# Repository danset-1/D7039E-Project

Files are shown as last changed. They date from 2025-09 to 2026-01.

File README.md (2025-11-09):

# D7039E Project - Swimming Timer
Accurate timing is a crucial part of both swimming competitions and training sessions. Existing professional timing systems are often reliable, but can be very expensive and difficult to set up, making them less accessible to smaller swimming clubs or individual athletes. This creates a need for a solution that is both affordable and adaptable while expanding on the idea of modern functionality.

The purpose of this project is to design and implement a modular timing system for swimming. The system will be built to provide accurate lap timing, digital tracking, and support for swimmer identification, so that personal bests and results can be stored and displayed in real time. 

# Rough sketch
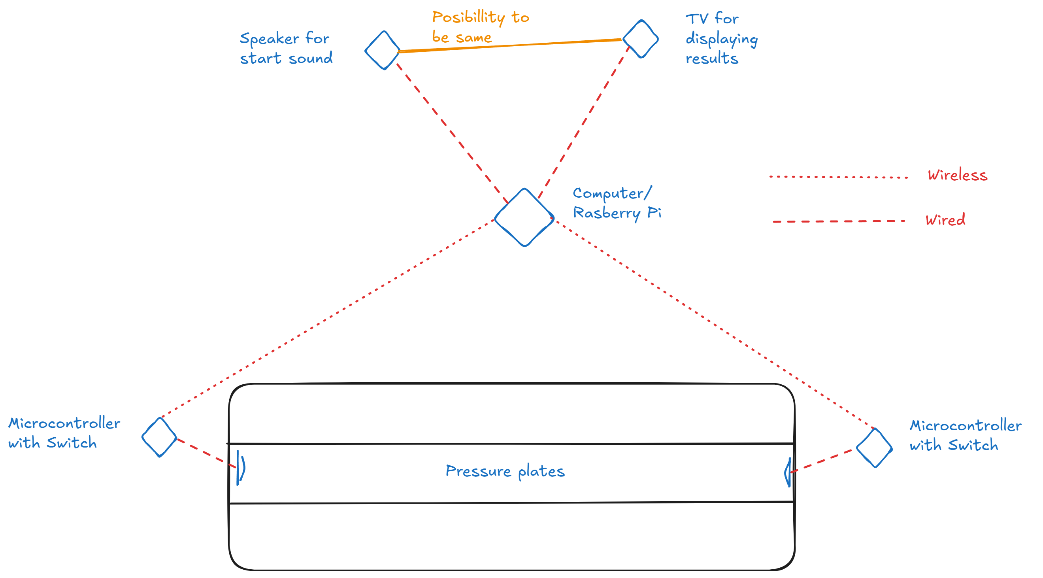
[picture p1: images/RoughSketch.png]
sketch


# Gantt Chart
https://ltuse-my.sharepoint.com/:x:/g/personal/gabsun-1_student_ltu_se/EYUQsI9EdhVLpdXC-OR69vYBhF8xrizb8_Dpn-aZufenOQ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

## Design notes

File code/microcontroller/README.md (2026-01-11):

# Microcontroller code
Code that runs on the microcontroller, the code auto runs on the Raspberry Pi Pico 2 W

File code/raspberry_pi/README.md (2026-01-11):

# Raspberry Pi code
Code that runs on the Raspberry Pi, program is started from running main.py

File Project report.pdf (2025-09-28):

# D7039E: Project report

### Swimming Timer

### Authors

gabsun-1@student.ltu.se
danset-1@student.ltu.se
olistr-1@student.ltu.se
jakkie-1@student.ltu.se

Github repository (https://github.com/danset-1/D7039E-Project)

### Department of Computer Science, Electrical and Space Engineering

### September 28, 2025

# Abstract

i

# Dedication

ii

# Declaration

iii

# Acknowledgements

iv

# Table of contents

Introduction | 1
1 Three Solutions | 1
2 Components | 3
3 Method | 5
4 Results | 6
5 Conclusion | 7
6 Project management | 8
7 GIT Workflow | 9
Appendix A | 10

v

# Abstract

vi

# Introduction

Accurate timing is a crucial part of both swimming competitions and training sessions. Existing professional timing systems are often reliable, but can be very expensive and difficult to set up, making them less accessible to smaller swimming clubs or individual athletes. This creates a need for a solution that is both affordable and adaptable while expanding on the idea of modern functionality.

The timers that are used in competitions today are touchpad system where a computer start measuring time when a start gun goes off. The swimming lanes have a touch pad on each side that sends a signal when pressure is applied which makes it so the timing system can make time splits for each distance of the swimming lane and in the end stop the time. They way the time is displayed to the spectators are there is some form of a big screen that shows a scoreboard where time splits are shown during the race and when the race finishes it shows all final times from fastest to slowest, making it easy to see who was fastest and being able to see everyone’s time.

The purpose of this project is to design and implement a modular timing system for swimming. The system will be built to provide accurate lap timing, digital tracking, and support for swimmer identification, so that personal bests and results can be stored and displayed in real time.

# Chapter 1

# Three Solutions

## 1.1 First idea

The first idea of how we could implement the timing system was a touchpad timing system like they use in official swimming competitions. These systems starts measuring time after a sound plays and at each end of the swimming lane there are touchpads. When a touchpad is pressed the timing computer gets a signal and can then either measure a time split or stop the time.

The advantages with using this solution are that the timing is extremely precise being able to measure time correctly down to hundredths of seconds. Another advantage is the system is easy to understand and to use, you start to swim when the sound goes off and then just touch the wall.

The negative with this solution is the price, these touchpad timing systems are really expensive, and they are also hard to install because you need a lot of technical knowledge and it needs maintenance. When installing this system you also need to perform many calibrations so that the touchpad does not get activated by mistake.

## 1.2 Second idea

The second idea was a solution including RFID tags to track the swimmer from the start, and to later check when the swimmer reaches the distance and when the swimmer gets back to the start. The idea was to implement it in a wristband or something similar so the swimmer’s location can easily be tracked.

One advantage of this solution is that it is easy to set up, and easy to use for the swimmer. It is also cheap compared to the first idea. This would also make swimmers able to track their own time without having to press a button.

The negative of this solution is that it is less accurate than the first idea, and that it might be uncomfortable or mess with the hydrodynamics of the swimmer by making the swimmer have more mass. Another problem is that the RFID (Radio Frequency Identification) signals could have reduced functionality underwater because of the water’s ability to absorb radio waves. This would

2 | CHAPTER 1. THREE SOLUTIONS

require a specific design for underwater swimming.

## 1.3 Third idea

Our final idea is the concept we have chosen to pursue. The system is designed to deliver accurate lap timing, digital tracking, and swimmer identification, allowing personal bests and results to be stored and displayed in real time.

The core of the system is a metal plate mounted on the swimming wall, leaving a small gap of one centimeter near the surface. Inside this gap, a switch is installed that registers when the plate is pushed. Each time this happens, the system receives a signal indicating that the swimmer has completed a lap. The race begins with a buzzer that simultaneously starts the swimmer’s timer, ensuring synchronized and reliable timing.
To keep costs flexible, the design allows each swimming lane to be equipped with either one or two timing plates, depending on the budget and the level of accuracy required.
All data processing and system control are managed by a central computer, making it possible to integrate with external displays and additional digital features. The ultimate goal is to create a modular and scalable system, suitable for everything from a single training lane to a full Olympicstandard pool, without the need for unnecessary hardware investments.

# Chapter 2

# Components

## 2.1 Computer

The plan is to use a small computer to run the main code on and that all of the microcontrollers will be communicating with and as well as displaying the times and results of the swimmers to a screen. We considered multiple different ones first we thought about using a Raspberry PI 4 it has an 1.8 Ghz CPU and it supports WiFi 2.4 and 5 GHz as well as Bluetooth 5.0 this is good as we planned to have the microcontroller and the Raspberrry PI connected thru WiFi. Raspberry PI 4 has two micro HDMI ports which makes it easy to connect to a screen, although micro HDMI might not be supported by all screens there are simple and easy adapters or micro HDMI to HDMI cables that can be used. However the Raspberry PI 4 does not have a built in real time clock which makes it hard for us to use when we need to be able to keep track of the swimmers times and a real time clock would make that much easier.

Then we thought of using the GIGA R1 WiFi Arduino which has a Cortex-M7 core at 480MHz and Cortex-M4at 240 MHz MCU. It supports WiFi 2.4GHz but not 5GHz and it also supports Bluetooth 5.0. This board also makes it so we can use WiFi between the computer and the microcontrollers even though 5GHz is not supported the communications will only need 2.4GHz. Unlike the Raspberry PI 4 the GIGA R1 does have a built in real time clock making it much easier to work with our project. However the GIGA R1 does not have any HDMI ports or any built in output for displaying to a screen and you need to buy extra equipment to be able to show it on a screen which makes it harder for us to be able to display the swimmers times and results.

So the one we ended up choosing was the Raspberry PI 5 which has a 2.4GHz CPU, it supports WiFi booth 2.4GHz and 5GHz as well as supporting Bluetooth 5. It also has two micro HDMI ports and also a built in real time clock. The Raspberry PI 5 has all of what we want WiFi so that we can communicate witch the microcontrollers and also the possiblility for Bluetooth, micro HDMI ports making it very easy to display the times and results of the swimmers as well as a built in real time clock.

## 2.2 Microcontroller

When we was choosing the microcontroller there were certain things we wanted it to have which were a good technical documentation, a strong community which would make it easier for us if we

4 | CHAPTER 2. COMPONENTS

ran into a problem or wonder about something there is a good chance someone have already gone thru the same thing. Also that it had a development board with WiFi and preferably a USB-C outlet.
| We considered between ESP32, ESP8266, RP2350 and decided to go with the RP2350 but
there are multiple different RP2350 boards first we considered the Raspberry PI Pico 2 W it has a really good price and it supports both WiFi 4 and Bluetooth, uses micro usb, it has a 4MB flash memory which makes it so you can easily put code on it however it has no microSD slot and also it needs additional hardware to be able to keep charging the battery.

The second RP2350 version we considered was a SparkFun RP2350 Thing Plus this one is quite bit more expensive than the Raspberry PI Pico, it uses a USB-C, it supports WiFi 4 and Bluetooth, it does have a microSD slot however no flash memory so it can have more memory but the memory is slower and consumes more battery. This board has onboard battery charging making it easy to recharge the battery.

The one we went with was the Challenger+ RP2350 WiFi6/BLE5, this microcontroller has USB-C, it supports WiFi 6 and Bluetooth 5.4, it has a battery charging circuit making it easy to recharge the battery, 4MB flash memory but no microSD slot. This microcontroller makes it so we can communicate with the computer using WiFi easy to recharge with USB-C and although it has limited memory size with 4MB it should be enough storage for us and as it is flash memory it has higher speeds and does not drain extra battery.

## 2.3 Limit switches

For the actual plate that will be pressed by the swimmers we will need limit switches which is the component that detects when the plate is pressed. The limit switch we want to use needs to be waterproof, relatively small and have an easy application which makes it easy to use. There are multiple different limit switches and first we considered using Stainless Steel Saftey Limit Switch with pin plunger these have a long life span so they could be used a long time without needing to be replaced, they also have a lot of safety certificates. However these were quite big at 110mm height and for us they were too big.
| Then we considered Honeywell 914CE1-9 Compact limit Switch these were very good with low
power consumption, also a lot of safety certificates, these also have a long life and 44mm in height which is small and nice. However these were almost three times the price of the limit switches we were looking at around 180 dollars a piece making them to expensive.
| The limit switch we went with was RS PRO Plunger Limit Switch made in stainless steel and
they are good in continuously water immersion which is perfect for us as these will be in water for long times, the height of them are 34mm which makes it easier to put them in our plates.

# Chapter 3

# Method

# Chapter 4

# Results

# Chapter 5

# Conclusion

# Chapter 6

# Project management

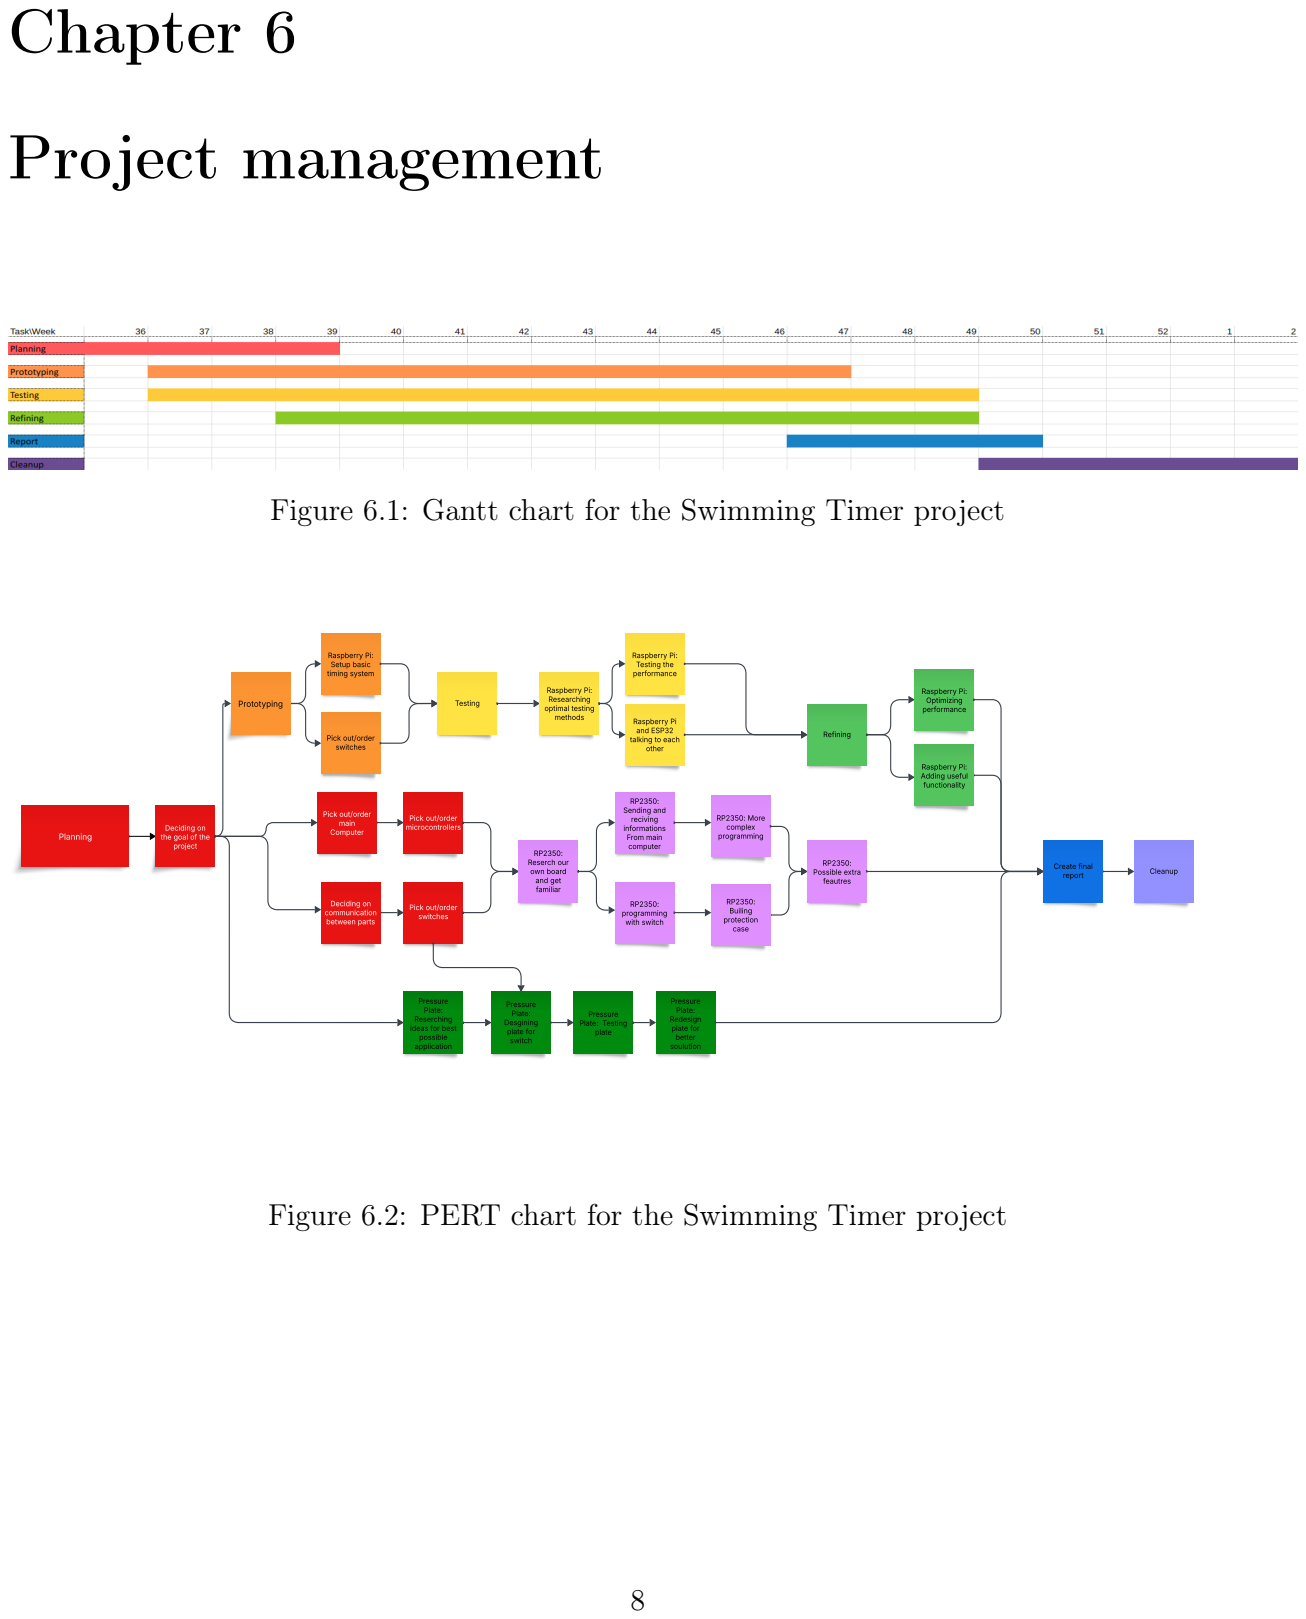
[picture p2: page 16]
Planning; Prototyping; Raspberry Pi: Setup basic timing system; Testing; Raspberry Pi: Testing the performance; Raspberry Pi: Researching optimal testing methods; RP2350: More complex programming; RP2350: programming with switch; RP2350: Sending and reciving informations From main computer; RP2350: Possible extra feautres; RP2350: Builing protection case; Pressure Plate: Testing plate; Deciding on communication between parts; Pressure Plate: Redesign plate for better soulution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

Figure 6.1: Gantt chart for the Swimming Timer project

Raspberry Pi
and ESP32
talking to each
other

Pick out/order
switches

main
Computer

microcontrollers

Deciding on
the goal of the
project

Figure 6.2: PERT chart for the Swimming Timer project

# Chapter 7

# GIT Workflow

# Appendix A

## Gabriel Sundblad

My name is Gabriel Sundblad, and I would describe myself as a social, curious, and goal-oriented person who thrives when faced with challenges and opportunities for personal growth. I am currently pursuing a Master of Science in Engineering, specializing in Computer Science at Luleå University of Technology (LTU), with a focus on industrial computer systems. My expected graduation is in May 2026.

Outside of my academic life, I have a wide range of interests that allow me to stay active and creative. Skiing, particularly downhill, has been an important part of my life for as long as I can remember. I have even competed in the sport, which has taught me discipline, perseverance, and the importance of continuous improvement. During the summer months, I enjoy spending time on the golf course, where patience and focus are key. Another passion of mine is cars and engines, I find it both exciting and inspiring to explore new technologies in this field, and sometimes I even make spontaneous visits to car dealerships just to learn more. However, my greatest interest is in computers and technology. My fascination with how they work has been the driving force behind my choice of education and my long-term career goals.

Through my studies, I have gained solid knowledge in various programming languages. Although I have worked with many, my personal favorites are Python and C++. I appreciate them because they combine simplicity with the potential to create highly complex and powerful solutions.

So far, my work experience has been outside of my field of study, including roles as a machine operator and logistics planner. Although different from computer science, these jobs have given me valuable transferable skills. I have learned to work effectively in teams, plan strategically, solve practical problems under pressure, and take responsibility in environments where accuracy and communication are crucial. I believe that these experiences provide me with a strong foundation for applying my technical skills in collaborative projects.

In this project course, my main ambition is to bridge the gap between my programming knowledge and real-world application. I want to develop my ability to use programming in practical scenarios, from initial design to implementation. I am also eager to work on creating something from scratch, gaining insight into the entire development process. Another important goal for me is to improve my presentation and communication skills, particularly when speaking in front of new groups and explaining technical concepts in a clear and engaging way.

I believe that my role in this project will be a combination of contributing to the design and structure of the solution, supporting the programming tasks, and taking an active part in presentations. By combining my technical interests with my previous work experience and my social skills, I aim to make a meaningful contribution to the project and to the team as a whole.

12 | APPENDIX A

## Jakob Kieri

My name is Jakob Kieri. I study for a Master of Science in Engineering, with a specialization in Industrial Computer Systems. Previously studied natural science at Tornedalsskolan, since I didn’t have access to university preparatory education with a focus on technology and had previously only dealt with a small amount of programming in Basic on a calculator. I am mostly interested in creating durable minimal systems that are reliable in fulfilling their goals, which is why I am interested in the programming language Rust and what the professor Per Lindgren does.

If I were to be more specific, I am not necessarily good at neither Rust nor programming, but if I want to learn a programming language it would need to be a language with a promising future and that would hopefully allow me to program it once and then be allowed to forget it even exists (because it fulfills its’ function so well).

But I have also taken optional courses that are not in Rust (Neural Networks and Learning Machines (D7046E) and Mechatronics (E7012E)) and am furthermore slightly interested in taking something like the course in Neuromorphic Computing (D7064E).

I am furthermore interested in a future where I get to tinker with a wide range of stuff (but I am drawn to having the programming language be Rust, whenever a programming language is needed (although ability to serve its’ function is still most important)): 3D-printing, self-hosting on a personal server, tinkering (fixing or improving items I have. For example, with exotic materials like, for example: PTFE, PBT, carbon fiber, and titanium (although stainless steel is very good for most circumstances)).

My main area of interest in the project is to figure out if the locally created RTIC Real Time Operating System can be used for this project. I expect various difficulties in getting everything to work and will spend my time on that. But I believe it is fitting for a project course at Luleå University of Technology, to try to incorporate what has been developed here. Furthermore, there is hope that the struggles will not be for nothing and that we will get more valuable experience.

There have furthermore consistently been and most probably will continue to be other roles that I am forced to in-officially hold in projects such as these. Among them includes being the one to remind others of requirements that are placed on us. I plan to lessen that role of mine, by clearly discussing and finding out what the group thinks about requirements and how the group wills to deal with them. I am not interested in a leader role or someone who has to constantly remind, instead I want to distribute load.

## Oliver Östrot

My name is Oliver Östrot, I was born in Västerås in the year 2002, and ever since I was little, I was interested in technology and computers. Previously, I studied information- and mediatechnology at Grillska Gymnasium, and then I continued with computer technology here at Luleå Technical University.

Spare time
In my spare time I like to play games, interact with people and occasionally go to the gym. I also like to watch series on Netflix and sometimes movies.

Previous work experience
I have not had any previous full time jobs, but I have had my fair share of summer jobs. I have worked as a cleaner for three summers in a row, and then afterwards i worked at GPV, as a planner where i managed work orders for the production. This year I worked as a fitter at ABB Robotics where I was assembling robots.

About the course
What I expect from the course is to get more familiar with working as a group and setting up and contributing to projects on a bigger scale. I would also like to learn more about sensors and more, work in practice on how to put things together to build something that can measure different factors such as time, and pressure more specifically in our project.

Work areas
During these upcoming months, i expect to get better at programming to hardware and software, learn more about how to set up hardware to solve the given problem with starting a timer when a certain signal goes off, where we should write code to get the timer to start at the same time for all swimmers. Thereafter the other part is fixing a pressure plate that stops the timer when the sensor is activated. This part is also very similar to the first part but with a pressure plate that activates the microcontroller through a sensor and not a signal. The work areas I am probably the worst in is connecting sensors and cables to the microcontroller and get that to then be connected properly so the response is working. On the contrary, I would say my strength is writing code in rust so that the program’s functions do what it is supposed to with the given input signal.

14 | APPENDIX A

## Daniel Sternelind

My name is Daniel Sternelind, 23 years old studying to become a Civil engineer in Computer science and previously I studied information- and mediatechnology at Berzeliusskolan Gymnasium.

In my spare time I enjoy going to the gym and being active. I like both watching and playing sports, I enjoy watching almost any sports and when it comes to playing them myself, right now I like to play disc golf. Some of my other interests are playing video games and spending time and socializing with friends.

When it comes to work experience I do not have any however during my time at university I have worked in projects before as well as a lot of laboratories which have been on a small and bigger scale. These have given me experience with working both alone and in groups, this has given me skills to be able to communicate and work effectively with others but also to be able to work individually.

I have always been interested in technology and computers and with my studies I have been able to learn a lot about both these things. The knowledge I have gained that will help me in this project is good knowledge of multiple programming languages, as well as a bit of knowledge about making hardware. In this course I expect to learn more and gain experience working in a group in a bigger project also planning the execution of our solution as well as having meetings with both the group and also the buyer of the project.

In this project my goals are to further my programming knowledge and gain more knowledge and experience with the actual hardware. Another goal is to gain experience with making code that then actual implements with the hardware and creates a good final product. My main area of interest in this project is how the pressure plates signalas will be able to communicate with our time keeping systems and how to be able to implement the programming for this. I am also interested in making a scoreboard where the times will be displayed.

I believe that in this project my main responsibility will be working with programming the software as I am more comfortable with programming than with building hardware. However, I also want to contribute to building and making the hardware in some way for this project in order to learn and gain more experience with hardware.

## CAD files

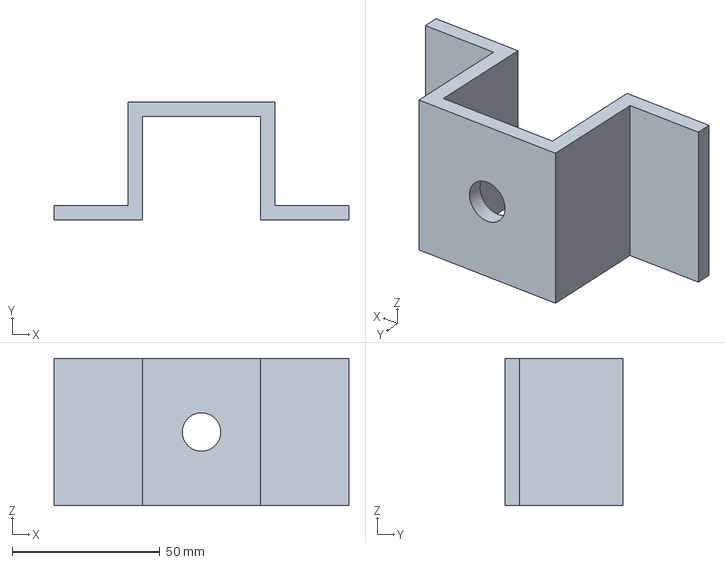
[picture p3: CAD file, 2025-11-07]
CAD/Limit switch holder.3mf
100.0 x 40.0 x 50.0 mm

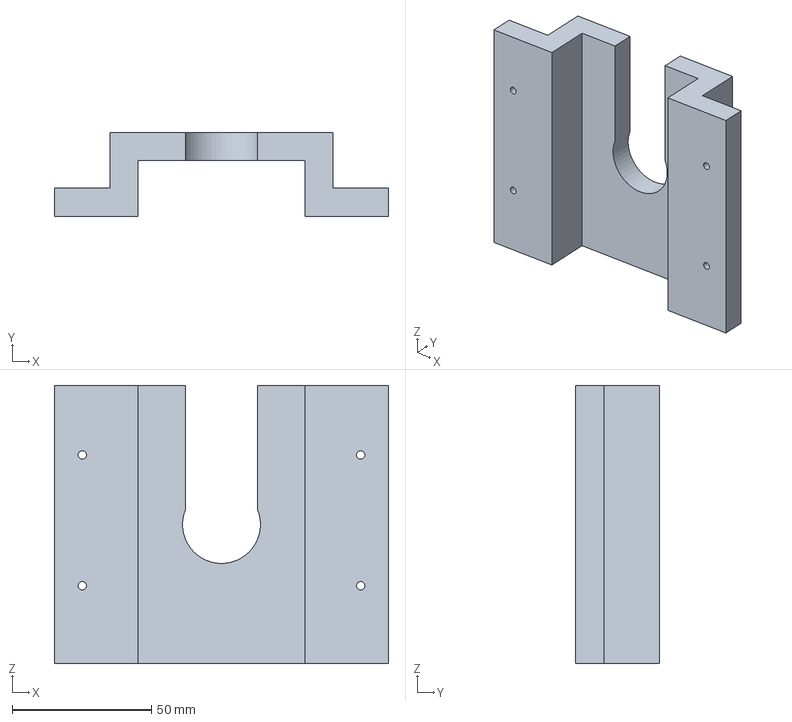
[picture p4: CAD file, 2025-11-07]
CAD/Suctioncup holder V2.3mf
120.0 x 30.0 x 100.0 mm

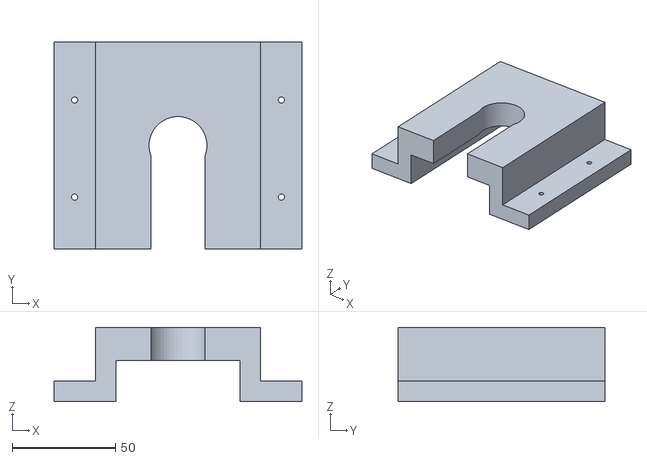
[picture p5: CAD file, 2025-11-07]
CAD/Suctioncup holder V2.1.stl
120.0 x 100.0 x 36.0

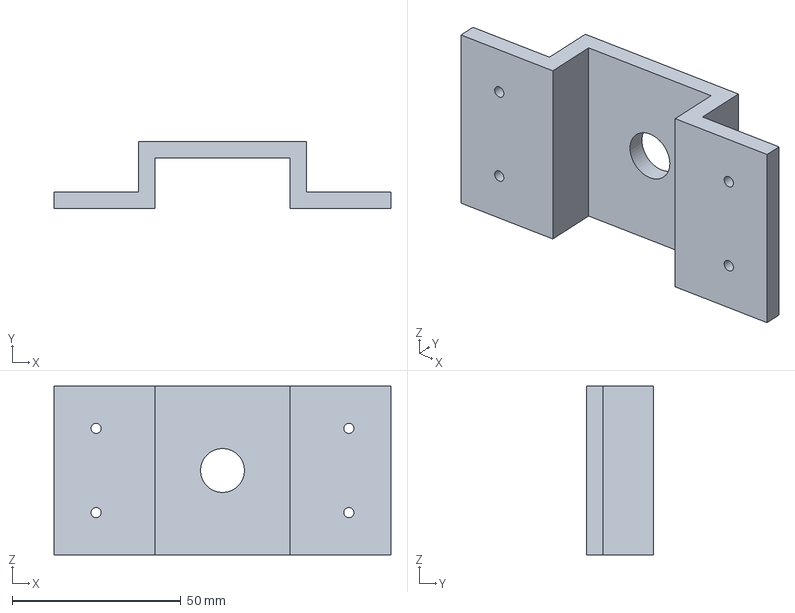
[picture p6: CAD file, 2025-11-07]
CAD/limit switch holder V2.3mf
100.0 x 20.0 x 50.0 mm

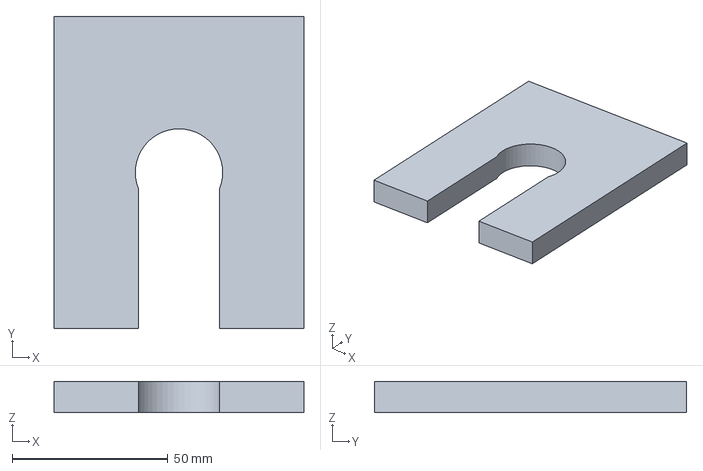
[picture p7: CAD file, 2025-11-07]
CAD/testing fitment V1.3mf
80.0 x 100.0 x 10.00 mm

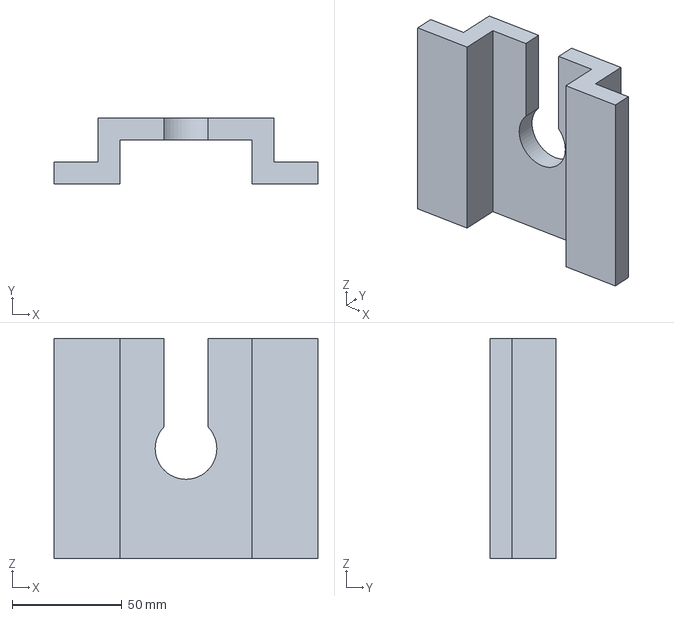
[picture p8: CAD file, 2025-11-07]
CAD/Suction cup holder.3mf
120.0 x 30.0 x 100.0 mm

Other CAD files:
CAD/Limit switch holderV1.0.3mf
CAD/Limit switch holder.stl
CAD/Limit switch holderV1.0.stl
CAD/Suction cup holder.stl
CAD/Suctioncup holder V2.stl
CAD/limit switch holder V2.stl
CAD/testing fitment V1.stl

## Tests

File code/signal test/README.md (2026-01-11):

# Test code for sending signals
Here there is code to test that the Raspberry Pi receives signals, from python code and rust code, The rust test was made beacuse at the start of the project we thought we were going to use rust but later decided to use python.

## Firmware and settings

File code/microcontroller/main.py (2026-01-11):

from machine import Pin
import time
import sys
import network
import socket
import json
import _thread

#Set pin 15 as PULL UP
switch = Pin(15, Pin.IN, Pin.PULL_UP)
stopwatch_Active = False

#Set Current time to 0
curTime = 0

#Turn LED on when powered
led = machine.Pin("LED", machine.Pin.OUT)
led.off()

#Connect to WiFi
SSID = "swim"
PASSWORD = "12345678"

wlan = network.WLAN(network.STA_IF)
wlan.disconnect()
wlan.active(True)
wlan.config(pm=0xa11140)
wlan.connect(SSID, PASSWORD)

print("Connecting to wifi...")
while not wlan.isconnected():
    time.sleep(0.5)
print("Connected:", wlan.ifconfig())
#LED on when connected to WiFi
led.on()

# Start stopwatch on microcontroller
class Stopwatch:
    def __init__(self, start_minutes, start_seconds):
        self.start_time = time.ticks_ms()
        self.time_offset = (start_minutes * 60 + start_seconds) * 1000
    
    def get_current_time(self):
        current_time = time.ticks_ms()
        elapsed_ms = time.ticks_diff(current_time, self.start_time) + self.time_offset
        return elapsed_ms / 1000.0
    
    def format_time(self, seconds):
        minutes = int(seconds // 60)
        seconds_remaining = seconds % 60
        return f"{minutes:02d}:{seconds_remaining:06.3f}"

def start_program(laps):
    global stopwatch_Active
    global curTime
    count = 0
    stopwatch_Active = True
    # Start Time
    start_time_minutes = 0
    start_time_seconds = 0
    # Sets start time to the set minutes and seconds
    stopwatch = Stopwatch(start_minutes=start_time_minutes, start_seconds=start_time_seconds)
    previous_state = switch.value()
    activated = False
    
    # Add cooldown
    last_press_time = 0
    delay = 0
    program_starttime = time.ticks_ms()
    initial_delay = 0
    
    # Initial time is set to the given time
    initial_time = start_time_minutes * 60 + start_time_seconds
    print(f"Start Time: {stopwatch.format_time(initial_time)}")
    print("------------------------------------------")
    
    try:
        while int(laps) > count and stopwatch_Active == True:
            # Update timer display
            current = stopwatch.format_time(stopwatch.get_current_time())
            curTime = current
            print(f"\rStopwatch: {current}", end='')
            
            # Check switch state
            current_state = switch.value()
            current_time_seconds = stopwatch.get_current_time()
            
            # Calculates time since start
            start_time = time.ticks_diff(time.ticks_ms(), program_starttime) / 1000.0
            
            # Check if switch is pressed
            if previous_state == 1 and current_state == 0:
                if not activated:
                    # Check for initial delay
                    if start_time >= initial_delay:
                        # Check for normal delay
                        last_press = current_time_seconds - last_press_time
                        #If it's a valid press send signal to Raspberry Pi with timestamp
                        if last_press >= delay:
                            print(f"\nTimestamp: {stopwatch.format_time(current_time_seconds)}")
                            last_press_time = current_time_seconds
                            activated = True

                            count+=1

                            HOST2 = "10.42.0.1"     #Raspberry Pi IP
                            PORT2 = 5000

                            data = {"id": "2", "command": "lap", "lap_time": current_time_seconds}
                            s = socket.socket(socket.AF_INET, socket.SOCK_STREAM)
                            s.connect((HOST2, PORT2))
                            s.sendall(json.dumps(data).encode("utf-8"))
                            s.close()
                            print("Sent:", data)
            
            # If switch is released
            elif previous_state == 0 and current_state == 1:
                activated = False  
            
            # Update state
            previous_state = current_state
            
            time.sleep_ms(5)
            
    except KeyboardInterrupt:
        stopwatch_Active = False
        print("\nStopped")
    finally:
        stopwatch_Active = False    


# Listen for signal from Raspberry Pi to start program and executing commands
def main():
    HOST = '0.0.0.0'
    PORT = 6000
    # Begin listening on port for signals
    s = socket.socket(socket.AF_INET, socket.SOCK_STREAM)
    s.setsockopt(socket.SOL_SOCKET, socket.SO_REUSEADDR, 1)
    s.bind((HOST, PORT))
    s.listen(1)
    print("Listening on port:", PORT)

    global stopwatch_Active
    global curTime
    try:
        # Check for a signal continuously
        while True:
            s.settimeout(1)
            try:
                conn, addr = s.accept()
            except OSError:
                # no incoming connection, just continue
                continue
            print("\nConnected by", addr)
            # Check if there is data with the signal and decode it
            try:
                data = conn.recv(1024)
                if not data:
                    conn.close()
                    continue
                msg = data.decode("utf-8")
                print("\nRecieved:", msg)
                # Based on what was recevied do different actions, Starting/Stopping/Reseting the race/timer
                try:
                    command = json.loads(msg)
                    laps = command.get("laps")
                    # If it's a start command create a thread that runs start_program function with amount of laps from signal
                    if command.get("command") == "start":
                        if stopwatch_Active == False:
                            _thread.start_new_thread(start_program, (laps,))
                        # If a new start command is received while a timer/race is still active ignore it
                        else:
                            print("ignoring command")

                    # Resets the timer/race and listens for a new signal
                    elif command.get("command") == "reset":
                        stopwatch_Active = False    # Stops the thread that is running start_program function
                        print("Timer reset")
                        print("\nListening on port:", PORT)

                    # Stops the timer and listens for new signal
                    elif command.get("command") == "stop":
                        stopwatch_Active = False
                        print("Timer stopped")
                        print("Listening on port:", PORT)
                        print("\n",curTime)
                    
                    # Unknow command if anything else
                    else:
                        print("Unknown command:", command)
                except Exception as e:
                    print("JSON Error:", e)
                conn.close()
            except Exception as e:
                print("Error:", e)
    except KeyboardInterrupt:
        stopwatch_Active = False
        print("\nStopped")

# Starts the code
main()
        

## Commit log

2025-09-15 I have done what I can
    Counsel with the group is necessary in order to further progress. I am powerless, especially because I don't want to be a dictator and am too weak to succeed in something in-between.
    [gantt 2.ods]
2025-11-07 Added file with switch input, and timer
2025-11-07 All different CAD mounts for our Pressure plate
    This is the CADing of our holders, and they have different variations
    [Limit switch holder.3mf, Limit switch holder.stl, Limit switch holderV1.0.3mf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]
2025-11-07 Start for communication
    Added connection between the swimtimer app and microcontroll, microcontroller file small test of sending signals when limit switch is activated
2025-11-11 Moved SwitchAndTimer and fixes
    Also fixed the delay to not register more than one click per 5 seconds, and fix so it is an initial 5 second cooldown
2025-11-11 Added connection
    Made it so you can send timestamps to Raspberry Pi, combined code from microcontroller.py into switch and timer and small changes to swimtimer
2025-11-12 Threaded Microcontroller
    Makes it so it keeps listening for commands while still running rest of the program.
2025-11-12 Reset command
    When timer is reset send signal to microcontroller to reset
2025-11-25 Added more commands
    made it possible to send more commands to microcontroller and sending multiple signals from raspberry pi at the same time
2025-11-25 updateUI
    added settings tab and other buttons, also made it so it starts in fullscreen (can be exited if you press "esc")
2025-12-03 Small fix for merge conflicts
    some parts got merged a bit wrong, this updates that so everything works
    [main.py]
2025-12-15 Added LED light, and flashed the microcontroller
    Added LED light if ON
